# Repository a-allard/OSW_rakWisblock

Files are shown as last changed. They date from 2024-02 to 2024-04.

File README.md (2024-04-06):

# OSW_rakWisblock

This project is a smart watch with the same outline as [watchy](https://github.com/sqfmi/watchy-hardware).  This uses a generic footprint that should work with any of the [RAK wisblock](https://docs.rakwireless.com/Product-Categories/WisDuo/) cores.  

### Supporting future development
If you like this project, please consider supporting my open source projects through:  (Note if you use the pcbway link below to order the project it does not cost you anymore but it does help me)
* "Buy Me A Coffee" (https://www.buymeacoffee.com/hwee)
* <a href="https://www.pcbway.com/project/shareproject/OSW_RAKwisBlock_543d8a2e.html">PCB from PCBWay</a>

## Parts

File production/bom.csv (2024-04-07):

Designator | Footprint | Quantity | Value | LCSC Part #
AN1 | MOLEX_1462350001_CHIP | 1 | 1.575GHz ANT | 1462350001
C1, C2, C3, C4, C5, C6, C7 | CAPC100X50X60L25N | 7 | 1u | GRM155R61H105ME05D
C10, C11, C12, C13 | CAPC100X50X60L25N | 4 | 1u | GRM155Z71A105KE01J
C15, C17, C19, C21, C23, C25, C29 | CAPC60X30X39L17L | 7 | 100n | GRM033Z71C104KE14D
C16_2 | CAPC60X30X39L17N | 1 | 1uF | GRM033D70J105ME01D
C16, C18, C20, C22, C24 | CAPC60X30X33L15L | 5 | 100p | GRM033R71H101KA12D
C26 | CAPC60X30X33L15L | 1 | 27p | GRM0335C1E270JA01D
C27, C30 | CAPC60X30X33L15L | 2 | 470p | GRM033R71H471KA12D
C28 | CAPC60X30X33L15L | 1 | 6.8n | GRM033R71E682KE14D
C31, C32 | CAPC40X20X22L10L | 2 | 10n | GRM022C71A103KE01L
C33, C34, C35, C36 | CAPC60X30X39L17L | 4 | 1uF | GRM033D70J105ME01D
C8, C9 | CAPC200X125X145L45N | 2 | 4.7u | GRM21BZ71H475ME15K
D1, D2, D3 | SOD370X155X135L32X57L | 3 | MBR0540T1G | MBR0580S1-7
J1 | TXGA_FBB04004-F40S1003K6M | 1 | WisBlock | FBB04004-F40S1003K6M
J2 | MOLEX_52435-2471 | 1 | 0524352471 | 0524352471
J4 | AMPHENOL_10114830-10102LF | 1 | 10114830-10102LF | 10114830-10102LF
J5 | GCT_USB3075-30-A | 1 | USB micro | USB3075-30-A
L2 | INDC400X400X120L120N | 1 | 10u | SRN4012BTA-100M
MP1, MP2, MP3, MP4 | MTGNP300H213Z565 | 4 | M3 1mm
Q1 | SOT23-3P65_210X110L20X32L | 1 | SI1308EDL-T1-GE3 | SI1308EDL-T1-GE3
R1, R2, R3, R5, R8 | RESC40X20X15L10N | 5 | 10k | ERJ-XGNF1002Y
R4 | RESC40X20X15L10N | 1 | 100k | ERJ-XGNF1003Y
R6 | RESC60X30X26L15L | 1 | 20k | ERJ-1GNF2002C
R7 | RESC40X20X15L10L | 1 | 10k | ERJ-XGNF1002Y
S1, S2 | Panasonic_EVQPUA02K | 2 | tactile_sw | EVQ-PUA02K
U1 | SOT23-5P95_270X145L35X35L | 1 | MCP73811T-420I/OT | MCP73811T-420I/OT
U2 | QFN29P50_500X500X80L55X25T325L | 1 | MAX2769B | MAX2769BETI/V+T
U3, U4 | SOT23-5P65_210X110L42X22L | 2 | MAX8510EXK29+T | MAX8510EXK29+T
U5 | SOT23-5P65_210X110L33X22N | 1 | MIC5365-3.0YC5-TR | MIC5365-3.0YC5-TR
Y1 | OSCDFN4_250X320X100L70X80L | 1 | TXETCDSANF-16.368000 | TXETCDSANF-16.368000

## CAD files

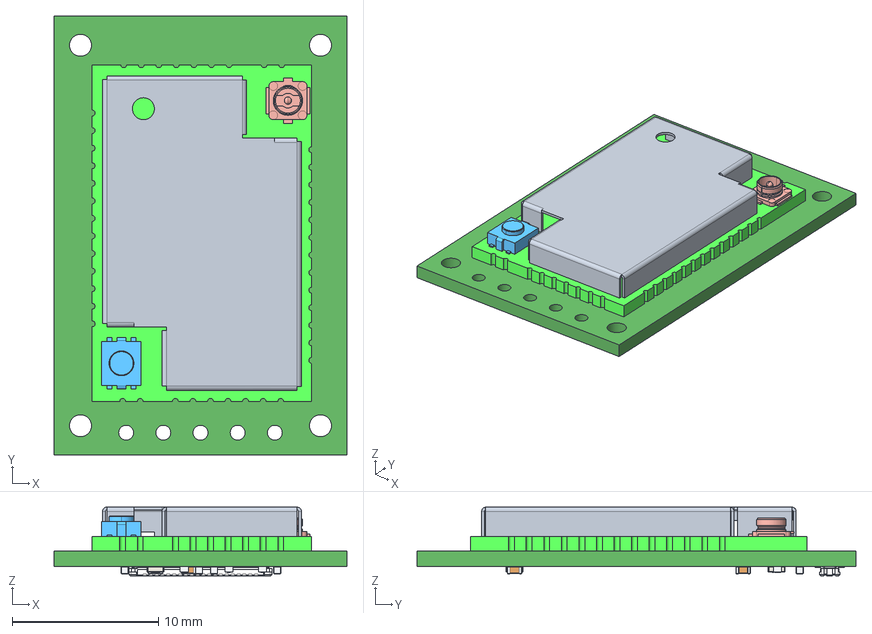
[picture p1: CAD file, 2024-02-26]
3D/3D_RAK11310.stp
20.0 x 30.0 x 4.70 mm
IPEX-FEMALE
RES_1005-0402 x 5
axe640124
C0402 x 6

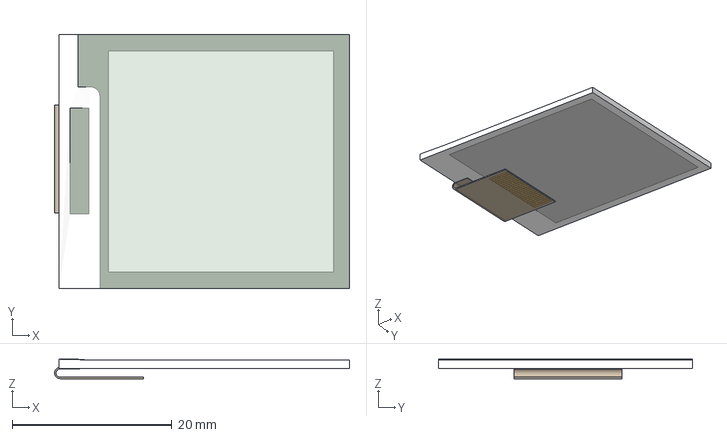
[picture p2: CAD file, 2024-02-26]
3D/Display.step
36.9 x 31.8 x 2.45 mm

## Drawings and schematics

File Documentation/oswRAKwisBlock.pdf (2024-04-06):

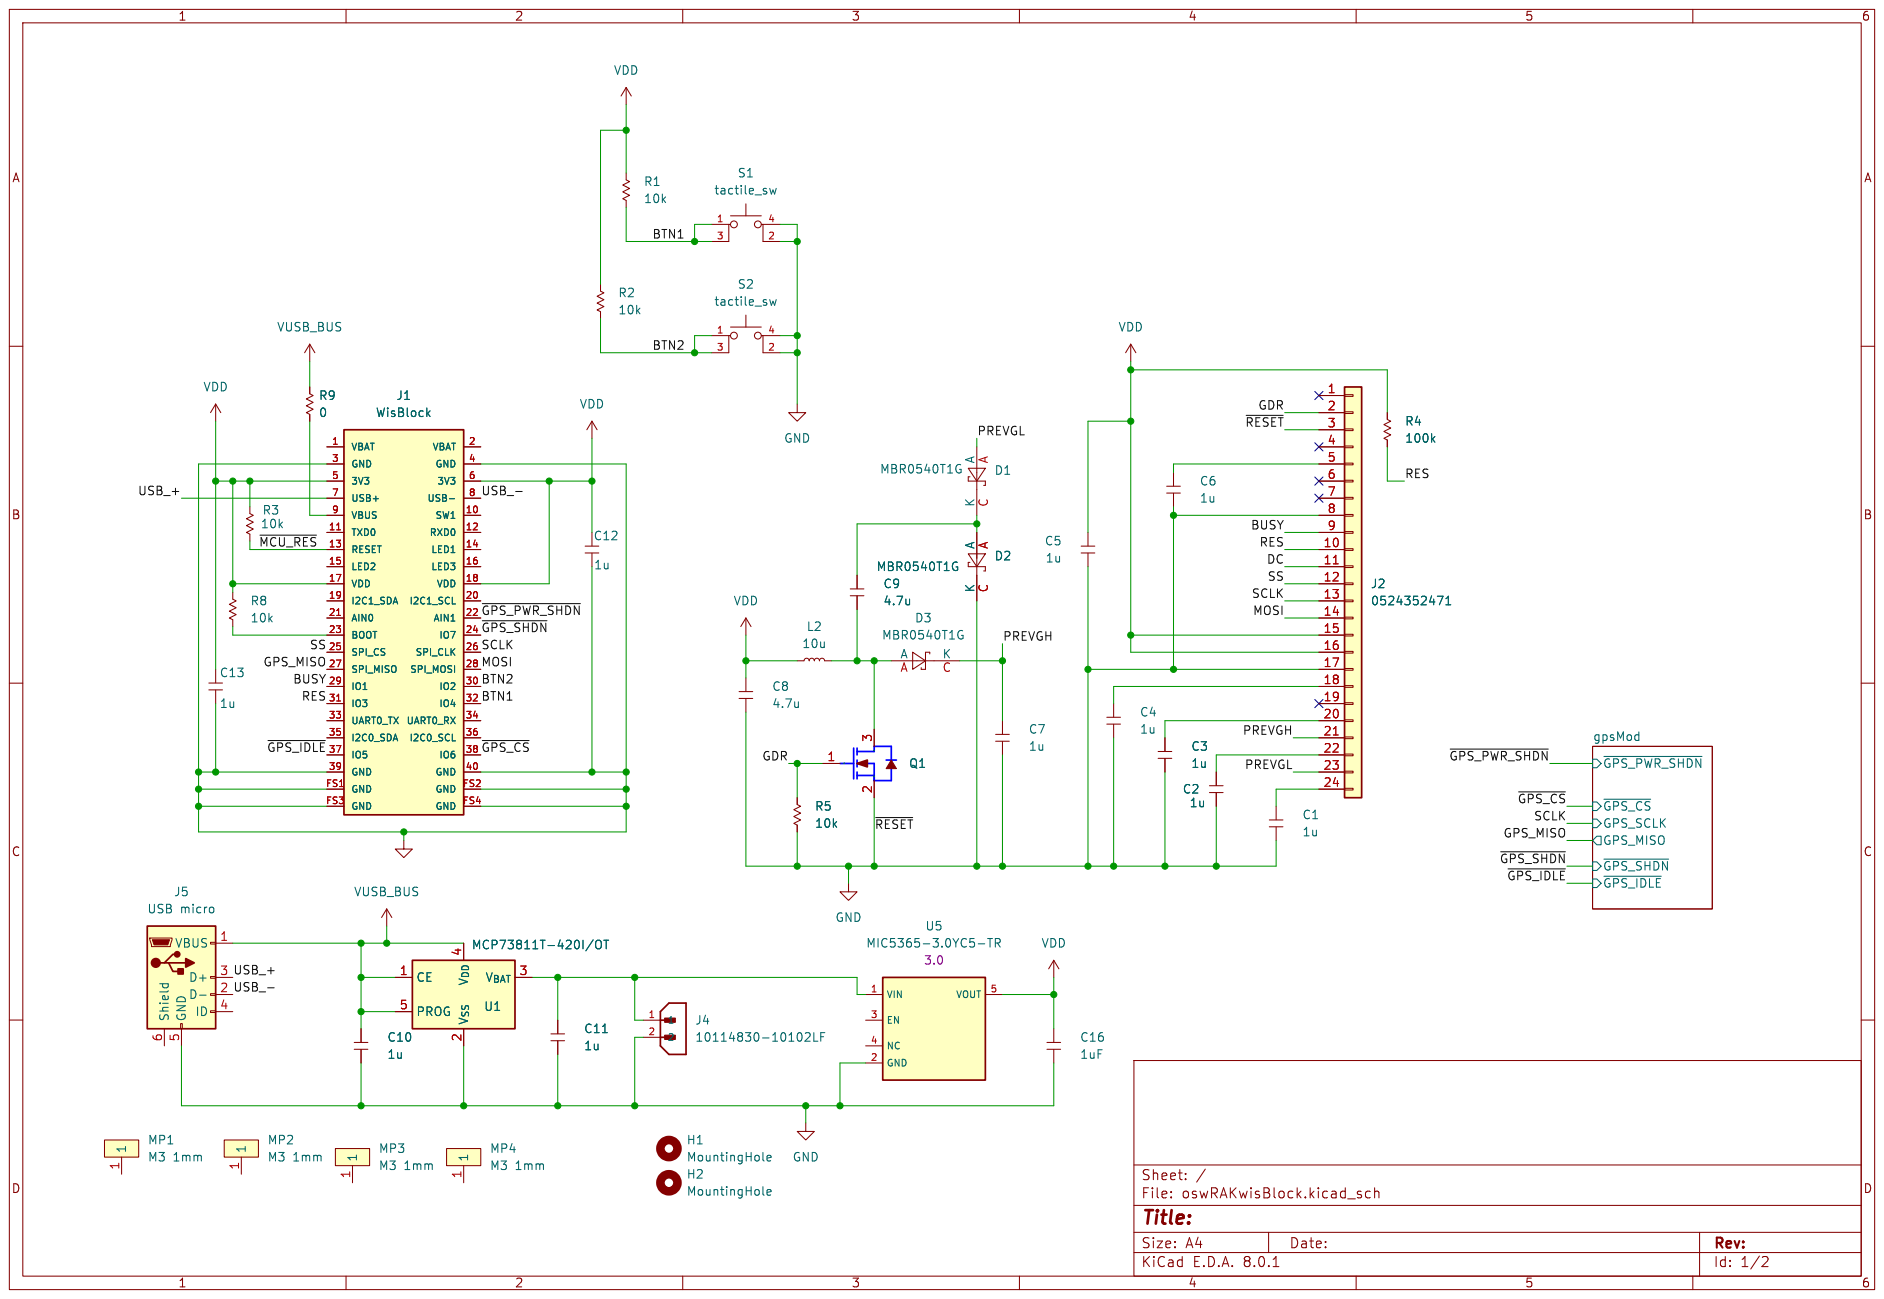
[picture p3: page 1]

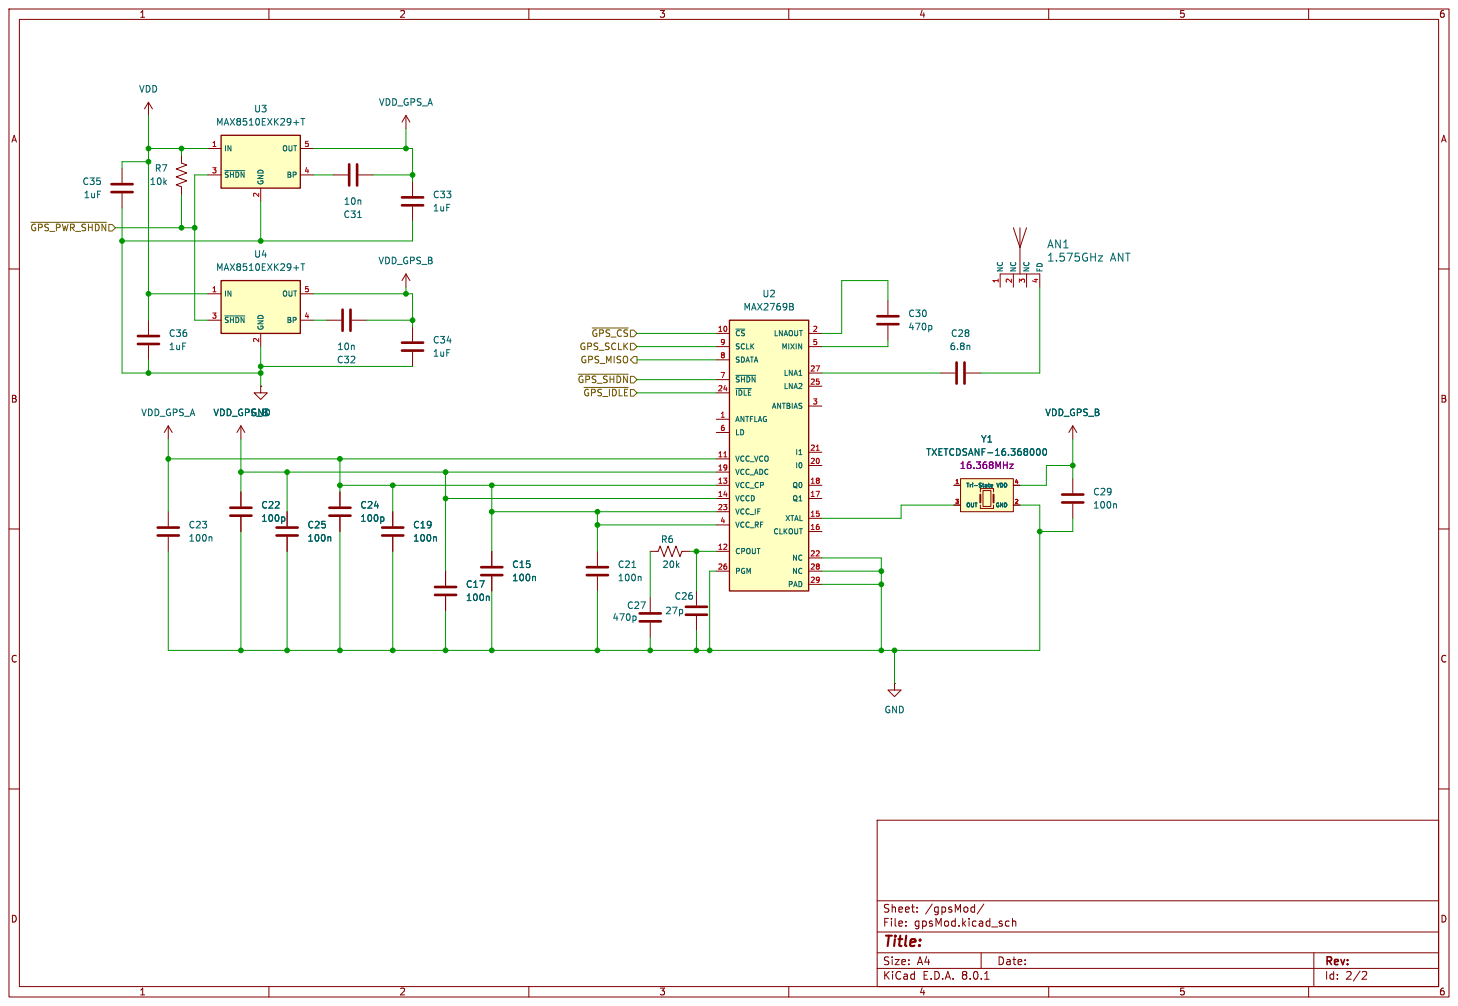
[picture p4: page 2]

Id: 2/2 Title: File: gpsMod.kicad_sch Sheet: /gpsMod/

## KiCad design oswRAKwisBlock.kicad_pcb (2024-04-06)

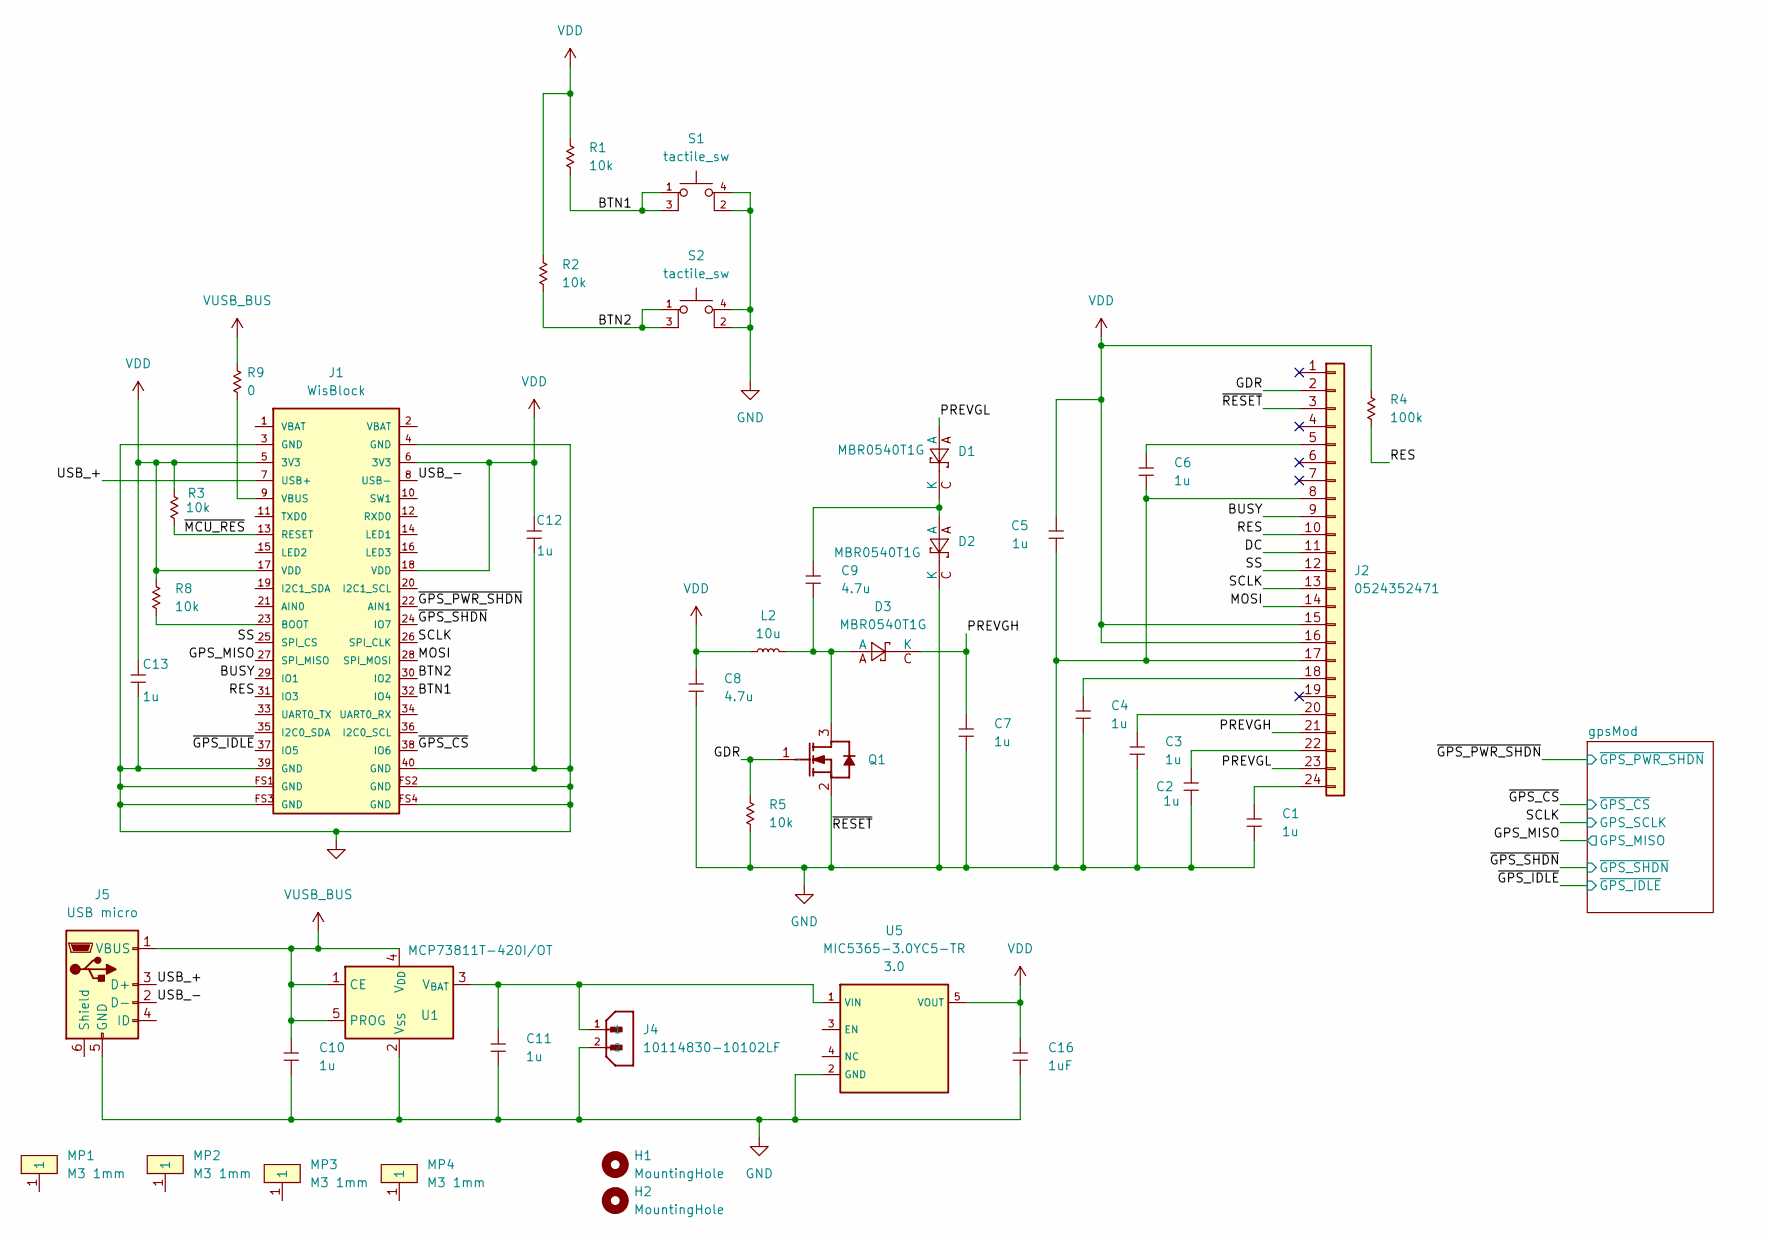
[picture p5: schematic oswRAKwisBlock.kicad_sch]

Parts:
C1, C2, C3, C4, C5, C6, C7: 1u; CAPC100X50X60L25N; Voltage 50V; Tolerance 20%; MPN GRM155R61H105ME05D
C8, C9: 4.7u; CAPC200X125X145L45N; Voltage 50V; Tolerance 20%; MPN GRM21BZ71H475ME15K
C10, C11, C12, C13: 1u; CAPC100X50X60L25N; Voltage 10V; Tolerance 10%; MPN GRM155Z71A105KE01J
C16: 1uF; CAPC60X30X39L17N; Voltage 6.3V; Tolerance 10%; MPN GRM033D70J105ME01D
D1, D2, D3: MBR0540T1G; SOD370X155X135L32X57L; Voltage 80V; MPN MBR0580S1-7
H1, H2: MountingHole; MountingHole_2.2mm_M2
J1: WisBlock; TXGA_FBB04004-F40S1003K6M; MPN FBB04004-F40S1003K6M
J2: 0524352471; MOLEX_52435-2471; MPN 0524352471
J4: 10114830-10102LF; AMPHENOL_10114830-10102LF; MPN 10114830-10102LF
J5: USB micro; GCT_USB3075-30-A; MPN USB3075-30-A
L2: 10u; INDC400X400X120L120N; Tolerance 20%; MPN SRN4012BTA-100M
MP1, MP2, MP3, MP4: M3 1mm; MTGNP300H213Z565
Q1: SI1308EDL-T1-GE3; SOT23-3P65_210X110L20X32L; Voltage 30V; MPN SI1308EDL-T1-GE3
R1, R2, R3, R5, R8: 10k; RESC40X20X15L10N; Tolerance 1%; MPN ERJ-XGNF1002Y
R4: 100k; RESC40X20X15L10N; Tolerance 1%; MPN ERJ-XGNF1003Y
R9: 0; RESC60X30X26L15N; Tolerance 1%; MPN ERJ-1GN0R00C
S1, S2: tactile_sw; Panasonic_EVQPUA02K; MPN EVQ-PUA02K
U1: MCP73811T-420I/OT; SOT23-5P95_270X145L35X35L; Voltage 3.75-6; MPN MCP73811T-420I/OT
U5: MIC5365-3.0YC5-TR; SOT23-5P65_210X110L33X22N; Voltage 3.0; MPN MIC5365-3.0YC5-TR

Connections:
/BTN1: J1.32 (IO4), R1.2, S1.1, S1.3 (K)
/BTN2: J1.30 (IO2), R2.2, S2.1, S2.3 (K)
/BUSY: J1.29 (IO1), J2.9
/DC: J2.11
/GDR: J2.2, Q1.1 (G), R5.1
/GPS_MISO: J1.27 (SPI_MISO); also elsewhere on the board
/MOSI: J1.28 (SPI_MOSI), J2.14
/PREVGH: C7.1, D3.C (K), J2.21
/PREVGL: D1.A, J2.23
/RES: J1.31 (IO3), J2.10, R4.2
/SCLK: J1.26 (SPI_CLK), J2.13; also elsewhere on the board
/SS: J1.25 (SPI_CS), J2.12
/USB_+: J1.7 (USB+), J5.3 (D+)
/USB_-: J1.8 (USB-), J5.2 (D-)
/~GPS_CS: J1.38 (IO6); also elsewhere on the board
/~GPS_IDLE: J1.37 (IO5); also elsewhere on the board
/~GPS_PWR_SHDN: J1.22 (AIN1); also elsewhere on the board
/~GPS_SHDN: J1.24 (IO7); also elsewhere on the board
/~MCU_RES: J1.13 (RESET), R3.2
GND: C1.2, C2.2, C3.2, C4.2, C5.2, C6.2, C7.2, C8.2, C10.2, C11.2, C12.2, C13.2, C16.2, D2.C (K), J1.3 (GND), J1.4 (GND), J1.39 (GND), J1.40 (GND), J1.FS1 (GND), J1.FS2 (GND), J1.FS3 (GND), J1.FS4 (GND), J2.3, J2.8, J2.17, J4.2, J5.5 (GND), Q1.2 (S), R5.2, S1.2, S1.4 (A), S2.2, S2.4 (A), U1.2 (V_{SS}), U5.2 (GND); also elsewhere on the board
unnamed: C9.1, D1.C (K), D2.A
unnamed: J1.23 (BOOT), R8.2
unnamed: J1.9 (VBUS), R9.2
unnamed: C6.1, J2.5
unnamed: C4.1, J2.18
unnamed: C3.1, J2.20
unnamed: C2.1, J2.22
unnamed: C1.1, J2.24
unnamed: C9.2, D3.A, L2.2, Q1.3 (D)
unnamed: C11.1, J4.1, U1.3 (V_{BAT}), U5.1 (VIN)
VDD: C5.1, C8.1, C12.1, C13.1, C16.1, J1.5 (3V3), J1.6 (3V3), J1.17 (VDD), J1.18 (VDD), J2.15, J2.16, L2.1, R1.1, R2.1, R3.1, R4.1, R8.1, U5.5 (VOUT); also elsewhere on the board
VUSB_BUS: C10.1, J5.1 (VBUS), R9.1, U1.1 (CE), U1.4 (V_{DD}), U1.5 (PROG)

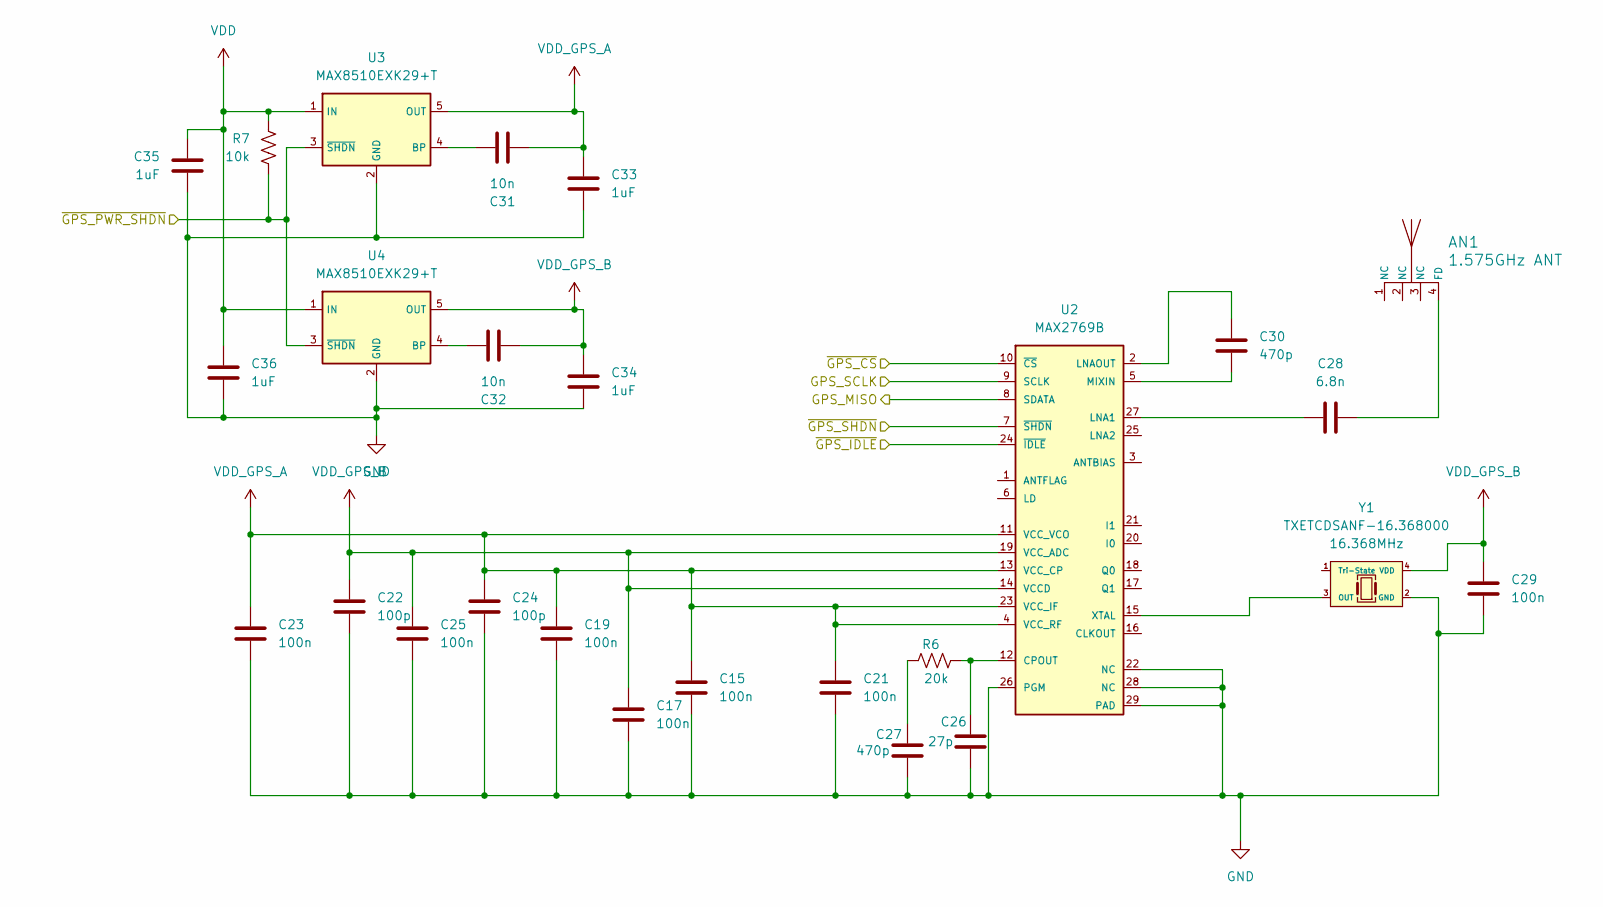
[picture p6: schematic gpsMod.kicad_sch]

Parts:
AN1: 1.575GHz ANT; MOLEX_1462350001_CHIP; MPN 1462350001
C15, C17, C19, C21, C23, C25, C29: 100n; CAPC60X30X39L17L; Voltage 16V; Tolerance 10%; MPN GRM033Z71C104KE14D
C22, C24: 100p; CAPC60X30X33L15L; Voltage 50V; Tolerance 10%; MPN GRM033R71H101KA12D
C26: 27p; CAPC60X30X33L15L; Voltage 25V; Tolerance 5%; MPN GRM0335C1E270JA01D
C27, C30: 470p; CAPC60X30X33L15L; Voltage 50V; Tolerance 10%; MPN GRM033R71H471KA12D
C28: 6.8n; CAPC60X30X33L15L; Voltage 25V; Tolerance 10%; MPN GRM033R71E682KE14D
C31, C32: 10n; CAPC40X20X22L10L; Voltage 50V; Tolerance 10%; MPN GRM022C71A103KE01L
C33, C34, C35, C36: 1uF; CAPC60X30X39L17L; Voltage 6.3V; Tolerance 10%; MPN GRM033D70J105ME01D
R6: 20k; RESC60X30X26L15L; Tolerance 1%; MPN ERJ-1GNF2002C
R7: 10k; RESC40X20X15L10L; Tolerance 1%; MPN ERJ-XGNF1002Y
U2: MAX2769B; QFN29P50_500X500X80L55X25T325L; MPN MAX2769BETI/V+T
U3, U4: MAX8510EXK29+T; SOT23-5P65_210X110L42X22L; Voltage 2.85V; MPN MAX8510EXK29+T
Y1: TXETCDSANF-16.368000; OSCDFN4_250X320X100L70X80L; Tolerance 2ppm; MPN TXETCDSANF-16.368000

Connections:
/GPS_MISO: U2.8 (SDATA); also elsewhere on the board
/SCLK: U2.9 (SCLK); also elsewhere on the board
/~GPS_CS: U2.10 (~CS); also elsewhere on the board
/~GPS_IDLE: U2.24 (~IDLE); also elsewhere on the board
/~GPS_PWR_SHDN: R7.2, U3.3 (~SHDN), U4.3 (~SHDN); also elsewhere on the board
/~GPS_SHDN: U2.7 (~SHDN); also elsewhere on the board
GND: C15.2, C17.2, C19.2, C21.2, C22.2, C23.2, C24.2, C25.2, C26.2, C27.2, C29.2, C33.2, C34.2, C35.2, C36.2, U2.22 (NC), U2.26 (PGM), U2.28 (NC), U2.29 (PAD), U3.2 (GND), U4.2 (GND), Y1.2 (GND); also elsewhere on the board
unnamed: AN1.4 (FD), C28.2
unnamed: C27.1, R6.1
unnamed: C26.1, R6.2, U2.12 (CPOUT)
unnamed: C28.1, U2.27 (LNA1)
unnamed: C30.1, U2.2 (LNAOUT)
unnamed: C30.2, U2.5 (MIXIN)
unnamed: U2.15 (XTAL), Y1.3 (OUT)
unnamed: C31.1, U3.4 (BP)
unnamed: C32.1, U4.4 (BP)
VDD: C35.1, C36.1, R7.1, U3.1 (IN), U4.1 (IN); also elsewhere on the board
VDD_GPS_A: C15.1, C19.1, C21.1, C23.1, C24.1, C31.2, C33.1, U2.4 (VCC_RF), U2.11 (VCC_VCO), U2.13 (VCC_CP), U2.23 (VCC_IF), U3.5 (OUT); also elsewhere on the board
VDD_GPS_B: C17.1, C22.1, C25.1, C29.1, C32.2, C34.1, U2.14 (VCCD), U2.19 (VCC_ADC), U4.5 (OUT), Y1.4 (VDD); also elsewhere on the board

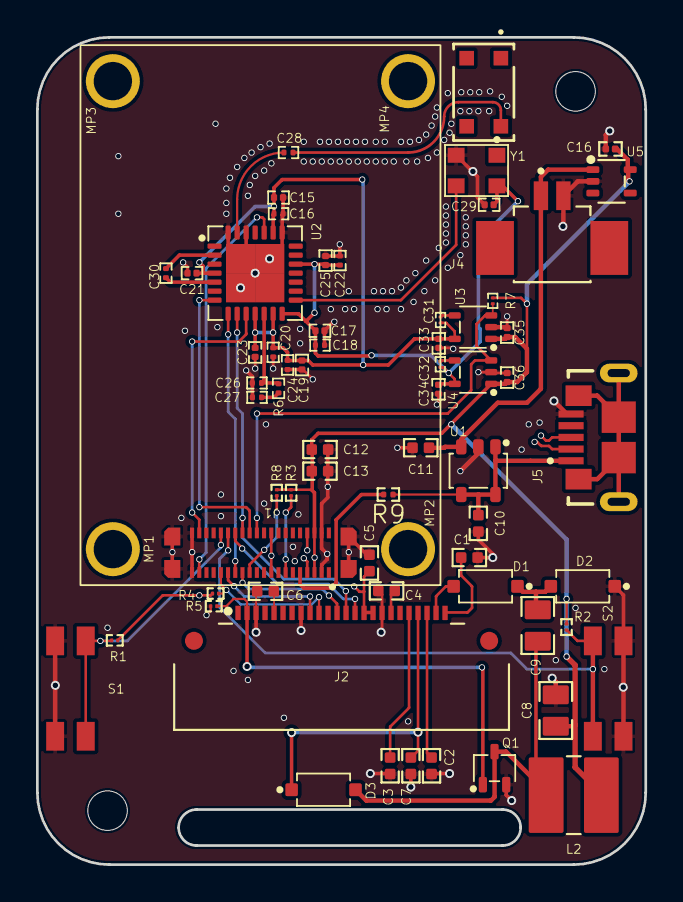
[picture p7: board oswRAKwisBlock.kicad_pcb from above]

Board: 4 copper layers, 33.8 x 46.0 mm, 69 parts (0 on the bottom side), 42 nets.

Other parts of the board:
C16#2, C18, C20: 100p; CAPC60X30X33L15L

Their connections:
GND: C16#2.2, C18.2, C20.2; also elsewhere on the board
VDD_GPS_A: C16#2.1, C20.1; also elsewhere on the board
VDD_GPS_B: C18.1; also elsewhere on the board

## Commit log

2024-02-03 kicad project start....
    [oswRAKwisBlock.kicad_pcb, oswRAKwisBlock.kicad_sch]
2024-02-03 Adding watchy outline.
    [oswRAKwisBlock.kicad_pcb]
2024-02-05 Adding connector.
    [oswRAKwisBlock.kicad_pcb, oswRAKwisBlock.kicad_sch]
2024-02-09 Getting the wisblock footprint on the board.
    [oswRAKwisBlock.kicad_pcb, oswRAKwisBlock.kicad_sch]
2024-02-11 Fixing the mounting hole issue.
    [oswRAKwisBlock.kicad_sch]
2024-02-15 Adding the FPs to the board.
    [oswRAKwisBlock.kicad_pcb]
2024-02-16 Working forward.
    [oswRAKwisBlock.kicad_pcb, oswRAKwisBlock.kicad_sch]
2024-02-24 Updating the board and moving some things around.
    [oswRAKwisBlock.kicad_pcb, oswRAKwisBlock.kicad_sch]
2024-02-25 Working on it....
    [oswRAKwisBlock.kicad_pcb, oswRAKwisBlock.kicad_sch]
2024-02-25 Working on getting the placement settled. VERY TIGHTgit pull!
    [oswRAKwisBlock.kicad_pcb, oswRAKwisBlock.kicad_sch]
2024-02-26 Adding a bunch of stuff to the design and some local models.
    [3D_RAK11310.stp, Display.step, oswRAKwisBlock.kicad_pcb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]
2024-02-27 Working on the board a bit more.
    [oswRAKwisBlock.kicad_pcb, oswRAKwisBlock.kicad_sch]
2024-03-13 Working on things.
    [oswRAKwisBlock.kicad_pcb, oswRAKwisBlock.kicad_sch]
2024-03-18 Finally got the GPS chip wired in. Just need to finish the pinout and then finalize the GPS part placement.
    [gpsMod.kicad_sch, oswRAKwisBlock.kicad_pcb, oswRAKwisBlock.kicad_sch]
2024-03-18 Made the RAK module semi transparent so I can layout the stuff underneath and check for collisions.
    [oswRAKwisBlock.kicad_pcb]
2024-03-19 Finished schematic. Time to layout.
    [gpsMod.kicad_sch, oswRAKwisBlock.kicad_pcb, oswRAKwisBlock.kicad_sch]
2024-03-20 Working on the layout a bit. Need confirmation on the USB port before I go much further.
    [oswRAKwisBlock.kicad_pcb]
2024-03-22 Moving parts around to start layout.
    [gpsMod.kicad_sch, oswRAKwisBlock.kicad_pcb, oswRAKwisBlock.kicad_sch]
2024-03-23 starting to lay the board out.
    [gpsMod.kicad_sch, oswRAKwisBlock.kicad_pcb, oswRAKwisBlock.kicad_sch]
2024-03-25 Moving some stuff around.
    [oswRAKwisBlock.kicad_pcb]
2024-03-25 Mirroring layout to match watchy layout better.
    [oswRAKwisBlock.kicad_pcb, oswRAKwisBlock.kicad_sch]
2024-03-26 Adding mounting holes.
    [oswRAKwisBlock.kicad_pcb, oswRAKwisBlock.kicad_sch]
2024-03-30 working on the layout some.
    [oswRAKwisBlock.kicad_pcb]
2024-03-31 Forgot to put the VBUS connection to the RAK mod. Done now.
    [oswRAKwisBlock.kicad_sch]
2024-03-31 Working on connect the dots.....
    [oswRAKwisBlock.kicad_pcb]
2024-04-01 playing with layout as it is very tight.
    [oswRAKwisBlock.kicad_pcb]
2024-04-06 Finishing up the layout.
    [oswRAKwisBlock.kicad_pcb, oswRAKwisBlock.kicad_sch]
2024-04-06 a couple minor tweaks to the layout (better trace connections) and moving a hole to be in the proper location
    [oswRAKwisBlock.kicad_pcb, oswRAKwisBlock.kicad_sch]
2024-04-06 Adding the html BOM and updating the pdf schematic (now moved to a correctly named folder.
2024-04-06 documentation update.
    [oswRAKwisBlock.kicad_pcb]
2024-04-06 Added production files
    [bom.csv, designators.csv, positions.csv]
